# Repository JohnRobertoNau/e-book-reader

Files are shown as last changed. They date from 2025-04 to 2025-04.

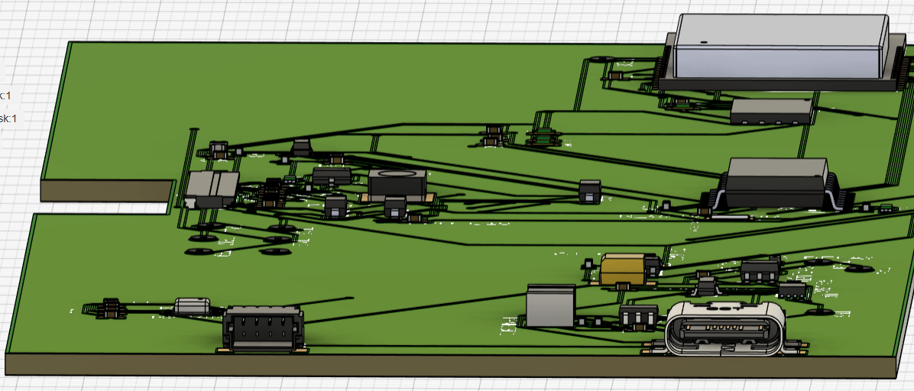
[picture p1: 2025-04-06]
Images/placa-3d-cu-componente_2.png

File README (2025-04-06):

Schema bloc si fisierul BOM se gasesc aici:
https://drive.google.com/drive/u/0/folders/1svHynGlwr7JKA02n5Jt7F-PYmH98pda1

Toate componentele au fost procurate de pe urmatoarele site-uri:
https://eu.mouser.com/
https://www.comet.srl.ro/

-------------------------------------------------------------------------------
Examinare 3D a dispozitivului:
 - pentru a vedea in Fusion ce este in spatele ecranului:
    apasa Hide pe Browser -> Bodies -> Box: vei vedea placuta si bateria

- Sketch 43 reprezinta bateria
- Sketch 44 reprezinta ecranul
- Pentru a vedea imagini cu dispozitivul cauta in directorul Images al acestui
repository

-------------------------------------------------------------------------------
Descriere Proiect:

OpenBook este un e-book reader open-source implementat pentru o citire simpla a
cartilor electronice. Pentru elaborarea acestui proiect au fost folosite
componente din biblioteca deskassistant. Erorile au fost verificate cu ajutorul
unui fisier de tip ".drc". Principala componenta este un microcontroller
ESP32-C6. Intregului dispozititv ii este asociat o baterie si un ecran, toate
acestea fiind amplasate intr-o carcasa, fiind vizibile in directorul Mechanical

-------------------------------------------------------------------------------
Componente Hardware folosite:
- ESP32-C6: Microcontroller principal, care asigura conectivitatea si
procesarea datelor.
- E-Paper Display: Display cu consum redus de energie, conectat prin
interfața SPI.
- Senzor de Mediu BME688: Masoara parametrii de mediu și trimite date
prin interfața I2C.
- Memorie NOR Flash 64MB: Stocare extensibila pentru fișiere de e-book.
- Modul RTC DS3231SN: Ofera funcționalitate de ceas în timp real.
- Conector USB-C: Incarcare și transfer de date.
- Baterie Li-Po: Alimentare principala a dispozitivului.
- Conectori pentru SD Card: Pentru extinderea memoriei si stocarea cartilor.

-------------------------------------------------------------------------------
ESP32-C6:
 - GPIO pinii sunt utilizați pentru conectarea senzorilor și a altor componente periferice.
 - SPI pentru E-Paper și memorie Flash.
 - I2C pentru senzorul de mediu.

Interfețe principale:
 - SPI: Conecteaza ecranul E-Paper și memoria Flash.
 - I2C: Conectează senzorul BME688 și modulul RTC.
 - UART: Pentru comunicație seriala.

Pini Utilizați - ESP32-C6:
 - GPIO16: TX pentru comunicație serială.
 - GPIO17: RX pentru comunicație serială.
 - GPIO21: SDA pentru I2C.
 - GPIO22: SCL pentru I2C.
 - GPIO18, GPIO19: SCK și MISO pentru SPI.
 - GPIO5: Chip Select pentru memorie Flash.
 - GPIO4: Reset pentru E-Paper.

 ------------------------------------------------------------------------------
 Probleme si gestionarea erorilor:

  - A fost necesara aprobarea a 2 erori de tip "smd-hole", deoarece piesa
  pentru J3 era defecta.
  - Pentru TP-uri a trebuit sa implementez propriul design.
  - Folosirea de VIAS-uri pentru a evita intersectia cablurilor.

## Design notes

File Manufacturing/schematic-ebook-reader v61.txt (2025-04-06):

Partlist exported from Fusion Hub: john   Project: Admin Project  Board: schematic-ebook-reader v61 at 4/6/2025 5:17 PM

Qty Value                                                                          Device                                                                         Package                                                Parts                                                                                                  Description                                                                                                                                                                                                                                                                                                                                                                                                                                                                                          ARROW_PART_NUMBER ARROW_PRICE-STOCK AVAILABILITY CENTROID_NOT_SPECIFIED CHECK_PRICES                                                                           COPYRIGHT                                                DATASHEET                              DESCRIPTION                                                                                        DIGIKEY_DESCRIPTION                                                                                                                                                                                                      DIGIKEY_PART_NUMBER                           HEIGHT                                                                                LEAD_FREE                                                          MANUFACTURER_NAME                 MANUFACTURER_PART_NUMBER MF                  MFR_NAME          MOUSER_PART_NUMBER    MOUSER_PRICE-STOCK                                                                                        MOUSER_TESTING_PART_NUMBER MOUSER_TESTING_PRICE-STOCK MP                                                                                                                  MPN                                                                                                  PACKAGE                     POPULARITY          PREFIX PRICE                        PROD_ID    PURCHASE-URL                                                                                                                                ROHS SNAPEDA_LINK                                                                       SPICEMODEL                                                                                                                                      SPICEPREFIX TEMPERATURE_RANGE_HIGH                                                                  TEMPERATURE_RANGE_LOW TP_SIGNAL_NAME VALUE             
1                                                                                  ADAFRUIT_LEDCHIP-LED0603                                                       ADAFRUIT_CHIP-LED0603                                  GHC_LED                                                                                                LED                                                                                                                                                                                                                                                                                                                                                                                                                                                                                                                                                                                                                                                                                                                                                                                                                                                                                                                                                                                                                                                                                                                                                                                                                                                                                                                                                                                                                                                                                                                                                                                                                                                                                                                                                                                                                                                                                                                                                                                                                                                                                                                                                                                                                                                                                                                                                                                                                                                                  
1                                                                                  SJ                                                                             SJ                                                     SJ1                                                                                                    SMD solder JUMPER                                                                                                                                                                                                                                                                                                                                                                                                                                                                                                                                                                                                                                                                                                                                                                                                                                                                                                                                                                                                                                                                                                                                                                                                                                                                                                                                                                                                                                                                                                                                                                                                                                                                                                                                                                                                                                  3                                                                                                                                                                                                                                                                                                                                                                                                                                                                                                                                                                                                                 
1   0.1uF/50V                                                                      ESP32_WROVER_EAGLE-LTSPICE_CC0402                                              ESP32_WROVER_EAGLE-LTSPICE_C0402                       EPD_C5                                                                                                 CAPACITOR, European symbol                                                                                                                                                                                                                                                                                                                                                                                                                                                                                                                                                                                                                                                                                                                                                                                                                                                                                                                                                                                                                                                                                                                                                                                                                                                                                                                                                                                                                                                                                                                                                                                                                                                                                                                                                                                                                                                                                                                                                                                                                                                                                                                                NONE                                                                                                                                            C                                                                                                                                                          
1   0.47                                                                           ESP32_WROVER_EAGLE-LTSPICE_RR0402                                              ESP32_WROVER_EAGLE-LTSPICE_C0402                       R3                                                                                                     RESISTOR, European symbol                                                                                                                                                                                                                                                                                                                                                                                                                                                                                                                                                                                                                                                                                                                                                                                                                                                                                                                                                                                                                                                                                                                                                                                                                                                                                                                                                                                                                                                                                                                                                                                                                                                                                                                                                                                                                                                                                                                                                                                                                                                                                                                                 NONE                                                                                                                                            R                                                                                                                                                          
1   100k                                                                           ESP32_WROVER_EAGLE-LTSPICE_RR0402                                              ESP32_WROVER_EAGLE-LTSPICE_C0402                       R1_PWRUSB                                                                                              RESISTOR, European symbol                                                                                                                                                                                                                                                                                                                                                                                                                                                                                                                                                                                                                                                                                                                                                                                                                                                                                                                                                                                                                                                                                                                                                                                                                                                                                                                                                                                                                                                                                                                                                                                                                                                                                                                                                                                                                                                                                                                                                                                                                                                                                                                                 NONE                                                                                                                                            R                                                                                                                                                          
8   100nF                                                                          ESP32_WROVER_EAGLE-LTSPICE_CC0402                                              ESP32_WROVER_EAGLE-LTSPICE_C0402                       C1, C2, C4_USB, C6, C8, C9, C10, C_DELAY                                                               CAPACITOR, European symbol                                                                                                                                                                                                                                                                                                                                                                                                                                                                                                                                                                                                                                                                                                                                                                                                                                                                                                                                                                                                                                                                                                                                                                                                                                                                                                                                                                                                                                                                                                                                                                                                                                                                                                                                                                                                                                                                                                                                                                                                                                                                                                                                NONE                                                                                                                                            C                                                                                                                                                          
1   100uF                                                                          RCL_CPOL-EUCT3528                                                              RCL_CT3528                                             C3                                                                                                     POLARIZED CAPACITOR, European symbol                                                                                                                                                                                                                                                                                                                                                                                                                                                                                                                                                                                                                                                                                                                                                                                                                                                                                                                                                                                                                                                                                                                                                                                                                                                                                                                                                                                                                                                                                                                                                                                                                                                                                                                                                                                                               0                                                                                                                                                                                                                                                                                                                                                                                                                                                      C                                                                                                                                                          
16  10k                                                                            ESP32_WROVER_EAGLE-LTSPICE_RR0402                                              ESP32_WROVER_EAGLE-LTSPICE_C0402                       R1, R1-PINH, R1_PINH1, R2-PINH, R2-PINH1, R4, R5, R6, R7, R8, R9, R10, R_BOOT, R_CHANGE, R_CL1, R_REST RESISTOR, European symbol                                                                                                                                                                                                                                                                                                                                                                                                                                                                                                                                                                                                                                                                                                                                                                                                                                                                                                                                                                                                                                                                                                                                                                                                                                                                                                                                                                                                                                                                                                                                                                                                                                                                                                                                                                                                                                                                                                                                                                                                                                                                                                                                 NONE                                                                                                                                            R                                                                                                                                                          
1   10uF                                                                           ESP32_WROVER_EAGLE-LTSPICE_CC0402                                              ESP32_WROVER_EAGLE-LTSPICE_C0402                       C7                                                                                                     CAPACITOR, European symbol                                                                                                                                                                                                                                                                                                                                                                                                                                                                                                                                                                                                                                                                                                                                                                                                                                                                                                                                                                                                                                                                                                                                                                                                                                                                                                                                                                                                                                                                                                                                                                                                                                                                                                                                                                                                                                                                                                                                                                                                                                                                                                                                NONE                                                                                                                                            C                                                                                                                                                          
1   112A-TAAR-R03_ATTEND                                                           112A-TAAR-R03_ATTEND                                                           112ATAARR03ATTEND                                      J4                                                                                                     Micro SD Card Socket, Push-Push Type, Top Mount, SMT, H=1.83mm, 10u                                                                                                                                                                                                                                                                                                                                                                                                                                                                                                                                                                                                                                                                                                 Micro SD Card Socket                                                                                Push-Push Type                                                                                                                                                                                                           Top Mount                                     SMT                                                                                   H=1.83mm                                                           10u                                                                           1.9mm                                   ATTEND                                                                                                    112A-TAAR-R03 ATTEND                                                                                                                                                                                                                                                                                                                                                                                                                                                                                                                                                                                                                                                                                                                                                                                                                                                                                                         
1   15                                                                             ESP32_WROVER_EAGLE-LTSPICE_RR0402                                              ESP32_WROVER_EAGLE-LTSPICE_C0402                       R_CAPACITOR                                                                                            RESISTOR, European symbol                                                                                                                                                                                                                                                                                                                                                                                                                                                                                                                                                                                                                                                                                                                                                                                                                                                                                                                                                                                                                                                                                                                                                                                                                                                                                                                                                                                                                                                                                                                                                                                                                                                                                                                                                                                                                                                                                                                                                                                                                                                                                                                                 NONE                                                                                                                                            R                                                                                                                                                          
1   1uF                                                                            ESP32_WROVER_EAGLE-LTSPICE_CC0402                                              ESP32_WROVER_EAGLE-LTSPICE_C0402                       C5                                                                                                     CAPACITOR, European symbol                                                                                                                                                                                                                                                                                                                                                                                                                                                                                                                                                                                                                                                                                                                                                                                                                                                                                                                                                                                                                                                                                                                                                                                                                                                                                                                                                                                                                                                                                                                                                                                                                                                                                                                                                                                                                                                                                                                                                                                                                                                                                                                                NONE                                                                                                                                            C                                                                                                                                                          
9   1uF/50V                                                                        ESP32_WROVER_EAGLE-LTSPICE_CC0402                                              ESP32_WROVER_EAGLE-LTSPICE_C0402                       EPD_C1, EPD_C2, EPD_C6, EPD_C7, EPD_C8, EPD_C9, EPD_C10, EPD_C11, EPD_C12                              CAPACITOR, European symbol                                                                                                                                                                                                                                                                                                                                                                                                                                                                                                                                                                                                                                                                                                                                                                                                                                                                                                                                                                                                                                                                                                                                                                                                                                                                                                                                                                                                                                                                                                                                                                                                                                                                                                                                                                                                                                                                                                                                                                                                                                                                                                                                NONE                                                                                                                                            C                                                                                                                                                          
1   2.2                                                                            ESP32_WROVER_EAGLE-LTSPICE_RR0402                                              ESP32_WROVER_EAGLE-LTSPICE_C0402                       R2                                                                                                     RESISTOR, European symbol                                                                                                                                                                                                                                                                                                                                                                                                                                                                                                                                                                                                                                                                                                                                                                                                                                                                                                                                                                                                                                                                                                                                                                                                                                                                                                                                                                                                                                                                                                                                                                                                                                                                                                                                                                                                                                                                                                                                                                                                                                                                                                                                 NONE                                                                                                                                            R                                                                                                                                                          
1   200                                                                            ESP32_WROVER_EAGLE-LTSPICE_RR0402                                              ESP32_WROVER_EAGLE-LTSPICE_C0402                       R1_BAT                                                                                                 RESISTOR, European symbol                                                                                                                                                                                                                                                                                                                                                                                                                                                                                                                                                                                                                                                                                                                                                                                                                                                                                                                                                                                                                                                                                                                                                                                                                                                                                                                                                                                                                                                                                                                                                                                                                                                                                                                                                                                                                                                                                                                                                                                                                                                                                                                                 NONE                                                                                                                                            R                                                                                                                                                          
2   20V/4.2A/52m?/1.4W                                                             ESP32_WROVER_SPARKFUN-DISCRETESEMI_MOSFET_PCH-DMG2305UX-7                      ESP32_WROVER_SPARKFUN-DISCRETESEMI_SOT23-3             Q1, Q2                                                                                                 P-channel MOSFETs                                                                                                                                                                                                                                                                                                                                                                                                                                                                                                                                                                                                                                                                                                                                                                                                                                                                                                                                                                                                                                                                                                                                                                                                                                                                                                                                                                                                                                                                                                                                                                                                                                                                                                                                                                                                                                                                                          TRAN-14388                                                                                                                                                                                                                                                                                                                                                                                                                                                                                                                              20V/4.2A/52m?/1.4W
1   2k                                                                             ESP32_WROVER_EAGLE-LTSPICE_RR0402                                              ESP32_WROVER_EAGLE-LTSPICE_C0402                       R2_BAT                                                                                                 RESISTOR, European symbol                                                                                                                                                                                                                                                                                                                                                                                                                                                                                                                                                                                                                                                                                                                                                                                                                                                                                                                                                                                                                                                                                                                                                                                                                                                                                                                                                                                                                                                                                                                                                                                                                                                                                                                                                                                                                                                                                                                                                                                                                                                                                                                                 NONE                                                                                                                                            R                                                                                                                                                          
5   4.7uF                                                                          ESP32_WROVER_EAGLE-LTSPICE_CC0402                                              ESP32_WROVER_EAGLE-LTSPICE_C0402                       C1_BAT, C1_BAT1, C1_BAT2, C2_BAT, C5_USB                                                               CAPACITOR, European symbol                                                                                                                                                                                                                                                                                                                                                                                                                                                                                                                                                                                                                                                                                                                                                                                                                                                                                                                                                                                                                                                                                                                                                                                                                                                                                                                                                                                                                                                                                                                                                                                                                                                                                                                                                                                                                                                                                                                                                                                                                                                                                                                                NONE                                                                                                                                            C                                                                                                                                                          
1   4.7uF/25V                                                                      ESP32_WROVER_EAGLE-LTSPICE_CC0402                                              ESP32_WROVER_EAGLE-LTSPICE_C0402                       C4                                                                                                     CAPACITOR, European symbol                                                                                                                                                                                                                                                                                                                                                                                                                                                                                                                                                                                                                                                                                                                                                                                                                                                                                                                                                                                                                                                                                                                                                                                                                                                                                                                                                                                                                                                                                                                                                                                                                                                                                                                                                                                                                                                                                                                                                                                                                                                                                                                                NONE                                                                                                                                            C                                                                                                                                                          
2   5k1                                                                            ESP32_WROVER_EAGLE-LTSPICE_RR0402                                              ESP32_WROVER_EAGLE-LTSPICE_C0402                       R2-USB, R2-USB1                                                                                        RESISTOR, European symbol                                                                                                                                                                                                                                                                                                                                                                                                                                                                                                                                                                                                                                                                                                                                                                                                                                                                                                                                                                                                                                                                                                                                                                                                                                                                                                                                                                                                                                                                                                                                                                                                                                                                                                                                                                                                                                                                                                                                                                                                                                                                                                                                 NONE                                                                                                                                            R                                                                                                                                                          
1   68uF                                                                           744043680IND_4828-WE-TPC_WRE                                                   IND_4828-WE-TPC_WRE                                    L1                                                                                                                                                                                                                                                                                                                                                                                                                                                                                                                                                                                                                                                                                                                                                                         Copyright (C) 2024 Ultra Librarian. All rights reserved.                                                                                                                                                                                                                                                                                                                                                                                                                                                                                                                                                                                                             744043680                                    Wurth Electronics                                                                                                                                                                                                                                                                                                                                                                                                                                                                                                                                                                                                                                                                                                                                                                                                                                                                                                                                                                                                                                                              
1   BD5229G-TR                                                                     BD5229G-TR                                                                     SOT95P280X125-5N                                       IC1                                                                                                    Voltage Detector with Adjustable Delay Time: CMOS processes are utilized to develop high precision, low current consumption CMOS reset ICs that allow arbitrary setting of the delay time. The extensive lineup includes both Nch Open Drain and CMOS output types in a wide range of detection voltages (from 2.3V to 6.0V, in 0.1V steps), enabling selection of the ideal solution based on customer requirements. In addition, the entire series is of course both lead-free and RoHS-compliant.                                                                                                                                                                                                                                                                Voltage Detector with Adjustable Delay Time: CMOS processes are utilized to develop high precision  low current consumption CMOS reset ICs that allow arbitrary setting of the delay time. The extensive lineup includes both Nch Open Drain and CMOS output types in a wide range of detection voltages (from 2.3V to 6.0V  in 0.1V steps)                                enabling selection of the ideal solution based on customer requirements. In addition  the entire series is of course both lead-free and RoHS-compliant.                                                            1.25mm                                ROHM Semiconductor    BD5229G-TR                                                                                                                                                      755-BD5229G-TR                                                                                                      https://www.mouser.co.uk/ProductDetail/ROHM-Semiconductor/BD5229G-TR?qs=4kLU8WoGk0vvnhrrYwdszw%3D%3D                                                                                                                                                                                                                                                                                                                                                                                                                                                                                                                                                                                                                                               
3   BUTTON_CUSYOMV1                                                                BUTTON_CUSYOMV1                                                                MYBUTTON                                               BOOT_BUTTON, CHANGE_BUTTON, REST_BUTTON                                                                                                                                                                                                                                                                                                                                                                                                                                                                                                                                                                                                                                                                                                                                                                                                                                                                                                                                                                                                                                                                                                                                                                                                                                                                                                                                                                                                                                                                                                                                                                                                                                                                                                                                                                                                                                                                                                                                                                                                                                                                                                                                                                                                                                                                                                                                                                                                                                                                                                                                     
1   CPH3225A                                                                       CPH3225A                                                                       CAPCP3225X100N                                         C10_SUPERCAP                                                                                           Cap 0.011F 3.3V 1210 Flat Check availability                                                                                                                                                                                                                                                                                                                                                                                                                                                                                             Not in stock                        https://www.snapeda.com/parts/CPH3225A/Seiko+Instruments/view-part/?ref=eda                                                                                                             11 mF (EDLC) Supercapacitor 3.3 V 1210 (3225 Metric) - -                                                                                                                                                                                                                                                                                                                                                                                                                                                                                                                                     Seiko Instruments                                                                                                                                                                                                           CPH3225A                                                                                                                                                                                                                 1210 Seiko                                             None                                    https://www.snapeda.com/api/url_track_click_mouser/?unipart_id=562593&manufacturer=Seiko Instruments&part_name=CPH3225A&search_term=None         https://www.snapeda.com/parts/CPH3225A/Seiko+Instruments/view-part/?ref=snap                                                                                                                                                                                                                                                                                                                  
1   DS3231SN#                                                                      DS3231SN#                                                                      SOIC127P1032X265-16N                                   U3                                                                                                     Real Time Clock Serial 16-Pin SOIC W T/R     Check availability                                                                                                                                                                                                                                                                                                                                                                                                                                                                          In Stock                            https://www.snapeda.com/parts/DS3231SN%23/Analog+Devices/view-part/?ref=eda                                                                                                             Extremely Accurate I2C-Integrated RTC/TCXO/Crystal                                                                                                                                                                                                                                                                                                                                                                                                                                                                                                                                           Analog Devices                                                                                                                                                                                                              DS3231SN#                                                                                                                                                                                                                SOIC-16 Maxim                                          None                                    https://www.snapeda.com/api/url_track_click_mouser/?unipart_id=99048&manufacturer=Analog Devices&part_name=DS3231SN#&search_term=None            https://www.snapeda.com/parts/DS3231SN%23/Analog+Devices/view-part/?ref=snap                                                                                                                                                                                                                                                                                                                  
1   ESP32-C6-WROOM-1-N8                                                            ESP32-C6-WROOM-1-N8                                                            XCVR_ESP32-C6-WROOM-1-N8                               U2                                                                                                     Check availability                                                                                                                                                                                                                                                                                                                                                                                                                                                                                                                       In Stock                            https://www.snapeda.com/parts/ESP32-C6-WROOM-1-N8/Espressif+Systems/view-part/?ref=eda                                                                                                  Multiprotocol Modules ESP32-C6 module                                                              Wi-Fi 6 in 2.4 GHz band                                                                                                                                                                                                  Bluetooth 5                                   Zigbee 3.0 and Thread. ESP34-WROOM Compatible - ENGINEERING SAMPLE                                                                                                                                                                                                             Espressif Systems                                                                                                                                                                                                                                                                                                                                                                                                    ESP32-C6-WROOM-1-N8        None                                                                                                                                                                                None                                                                                                                                                                                                                                                https://www.snapeda.com/parts/ESP32-C6-WROOM-1-N8/Espressif+Systems/view-part/?ref=snap                                                        
1   ESP32C6_VARISTORCN1812                                                         ESP32C6_VARISTORCN1812                                                         ESP32C6_VARISTOR_CT/CN1812                             PFMF.050.1                                                                                             VARISTOR                                                                                                                                                                                                                                                                                                                                                                                                                                                                                                                                                                                                                                                                                                                                                                                                                                                                                                                                                                                                                                                                                                                                                                                                                                                                                                                                                                                                                                                                                                                                                                                                                                                                                                                                                                                                                                           0                                                                                                                                                                                                                                                                                                                                                                                                                                                                                                                                                                                                                 
2   ESP32_WROVER_AVX---SD0805S020S1R0_AVX_SD0805S020S1R0_0_0AVX_SD0805S020S1R0_0_0 ESP32_WROVER_AVX---SD0805S020S1R0_AVX_SD0805S020S1R0_0_0AVX_SD0805S020S1R0_0_0 ESP32_WROVER_AVX---SD0805S020S1R0_AVX_SD0805S020S1R0_0 D2, D7                                                                                                 Schottky Barrier Rectifier Diode                                                                                                                                                                                                                                                                                                                                                                                                                                                                                                                      No                                                                                                                                                                     http://datasheets.avx.com/schottky.pdf                                                                                                    DIODE SCHOTTKY 20V 1A 0805                                                                                                                                                                                               478-7800-1-ND                                                                                                                       yes                                                                                                                           AVX                                   581-SD0805S020S1R0                                                                                                                                                                                                                                                                                                                                                                                             0805 (2012 metric)                              D                                                                                                                                                                                          yes                                                                                                                                                                                                                                                 +125°C                                                                                  -55°C                                                  
1   ESP32_WROVER_BME680_BME680                                                     ESP32_WROVER_BME680_BME680                                                     ESP32_WROVER_BME680_PSON80P300X300X100-8N              SENSOR2                                                                                                Integrated Environmental Unit                                                                                                                                                                                                                                                                                                                                                                                                                                                                                                            Unavailable                                                                                                                                                                                                                 Integrated Environmental Unit                                                                                                                                                                                                                                                                                                                                                                                                                                                                                                                                                                Bosch Sensortec                                                                                                                                                                                                             BME680                                                                                                                                                                                                                   LGA-8 Bosch Tools                                      None                                                                                                                                                                                                                                                                                                                                                                                                                                                                                                                                                                                   
1   ESP32_WROVER_SPARKFUN-IC-POWER_MCP73831                                        ESP32_WROVER_SPARKFUN-IC-POWER_MCP73831                                        ESP32_WROVER_SPARKFUN-IC-POWER_SOT23-5                 MCP73831                                                                                               MCP73831T Li-Ion, Li-Pol Controller                                                                                                                                                                                                                                                                                                                                                                                                                                                                                                                                                                                                                                                                                                                                                                                                                                                                                                                                                                                                                                                                                                                                                                                                                                                                                                                                                                                                                                                                                                                                                                                                                                                                                                                                                                                                                                                                        IC-09995                                                                                                                                                                                                                                                                                                                                                                                                                                                                                                                                                  
1   FH34SRJ-24S-0.5SH_99_                                                          FH34SRJ-24S-0.5SH_99_                                                          FH34SRJ24S05SH99                                       J1                                                                                                     24 Position FFC, FPC Connector Contacts, Top and Bottom 0.020" (0.50mm) Surface Mount, Right Angle                                                                                                                                                                                                                                                                                                                                                                                                                                                                                                                                                                                                                                                                  24 Position FFC                                                                                     FPC Connector Contacts                                                                                                                                                                                                   Top and Bottom 0.020" (0.50mm) Surface Mount  Right Angle                                                                                                                                                                               1.1mm                                        Hirose            FH34SRJ-24S-0.5SH(99)                                                                                                                                      798-FH34SRJ24S05SH99       https://www.mouser.co.uk/ProductDetail/Hirose-Connector/FH34SRJ-24S-0.5SH99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                                                                                                                                                                                                                                                                                                                                                                                                                                                                                                                                                                                                                                                                                                                                                    
1   MAX17048G+T10                                                                  MAX17048G+T10                                                                  SON50P200X200X80-9N                                    U4                                                                                                     Check availability                                                                                                                                                                                                                                                                                                                                                                                                                                                                                                                       In Stock                            https://www.snapeda.com/parts/MAX17048G+T10/Analog+Devices/view-part/?ref=eda                                                                                                           3µA 1-Cell/2-Cell Fuel Gauge with ModelGauge                                                                                                                                                                                                                                                                                                                                                                                                                                                                                                                                                 Analog Devices                                                                                                                                                                                                              MAX17048G+T10                                                                                                                                                                                                            TDFN-8 Maxim                                           None                                    https://www.snapeda.com/api/url_track_click_mouser/?unipart_id=329239&manufacturer=Analog Devices&part_name=MAX17048G+T10&search_term=None       https://www.snapeda.com/parts/MAX17048G+T10/Analog+Devices/view-part/?ref=snap                                                                                                                                                                                                                                                                                                                
3   MBR0530                                                                        MBR0530                                                                        SOD3716X135N                                           D3, D4, D5                                                                                             ON SEMICONDUCTOR - MBR0530 - DIODE, SCHOTTKY, 0.5A, 30V, SOD-123                                                                                                                                                                                                                                                                                                                                                                                                                                                                         In Stock                            https://www.snapeda.com/parts/MBR0530/Onsemi/view-part/?ref=eda                                                                                                                         Diode Schottky 30 V 500mA Surface Mount SOD-123                                                                                                                                                                                                                                                                                                                                                                                                                                                                                                                                              ON Semiconductor                                                                                                                                                                                                            MBR0530                                                                                                                                                                                                                  SOD-123-2 ON Semiconductor                             None                                    https://www.snapeda.com/api/url_track_click_mouser/?unipart_id=179458&manufacturer=ON Semiconductor&part_name=MBR0530&search_term=None           https://www.snapeda.com/parts/MBR0530/Onsemi/view-part/?ref=snap                                                                                                                                                                                                                                                                                                                              
6   PGB1010603MR                                                                   PGB1010603MR                                                                   DIOC1608X36N                                           D6, D8, D9, D10, D11, D12                                                                              Check availability                                                                                                                                                                                                                                                                                                                                                                                                                                                                                                                       In Stock                            https://www.snapeda.com/parts/PGB1010603MR/Littelfuse/view-part/?ref=eda                                                                                                                150V (Typ) Clamp - Ipp Tvs Diode Surface Mount 0603 (1608 Metric)                                                                                                                                                                                                                                                                                                                                                                                                                                                                                                                            Littelfuse Inc.                                                                                                                                                                                                             PGB1010603MR                                                                                                                                                                                                             0603 Littelfuse Inc.                                   None                                    https://www.snapeda.com/api/url_track_click_mouser/?unipart_id=5659453&manufacturer=Littelfuse Inc.&part_name=PGB1010603MR&search_term=None      https://www.snapeda.com/parts/PGB1010603MR/Littelfuse/view-part/?ref=snap                                                                                                                                                                                                                                                                                                                     
1   QWIIC_RIGHT_ANGLE                                                              QWIIC_CONNECTORJS-1MM                                                          JST04_1MM_RA                                           J3                                                                                                     SparkFun I2C Standard Qwiic Connector                                                                                                                                                                                                                                                                                                                                                                                                                                                                                                                                                                                                                                                                                                                                                                                                                                                                                                                                                                                                                                                                                                                                                                                                                                                                                                                                                                                                                                                                                                                                                                                                                                                                                                                                                                                                                                                                      CONN-13694                                                                                                                                                                                                                                                                                                                                                                                                                                                                                                                              QWIIC_RIGHT_ANGLE 
1   SAMACSYS_PARTS_USB4110-GF-A                                                    SAMACSYS_PARTS_USB4110-GF-A                                                    SAMACSYS_PARTS_USB4110GFA                              J2                                                                                                     CONN USB 2.0 TYPE-C R/A SMT                                                                                                                                                                                                                                                                                                                                                                                                                                                                                                                                                                                                                                                                                                                                         CONN USB 2.0 TYPE-C R/A SMT                                                                                                                                                                                                                                                                                                                                               3.26mm                                                                                                                                                   GCT (GLOBAL CONNECTOR TECHNOLOGY) USB4110-GF-A                                                   640-USB4110-GF-A      https://www.mouser.co.uk/ProductDetail/GCT/USB4110-GF-A?qs=KUoIvG%2F9IlYiZvIXQjyJeA%3D%3D
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

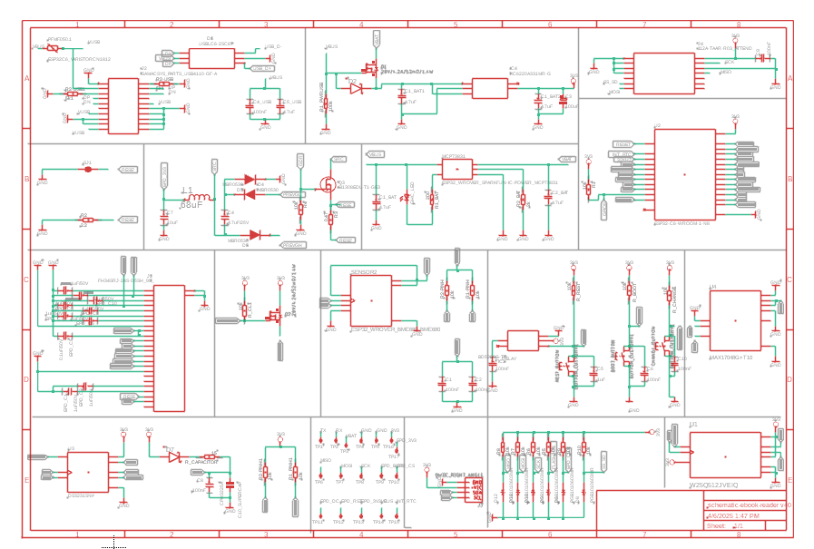
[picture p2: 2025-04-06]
Images/schematic.png

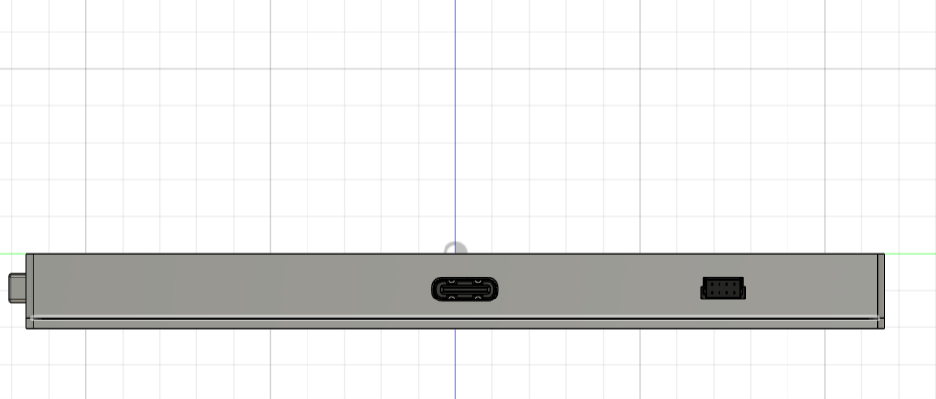
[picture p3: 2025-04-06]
Images/porturi-laterale+butoane.png

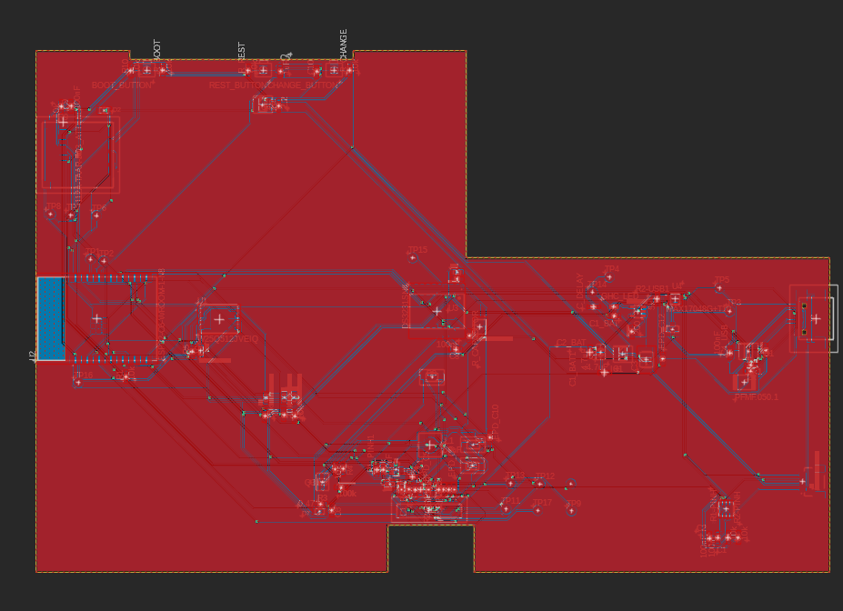
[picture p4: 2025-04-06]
Images/pcb-cu-plan-de-masa.png

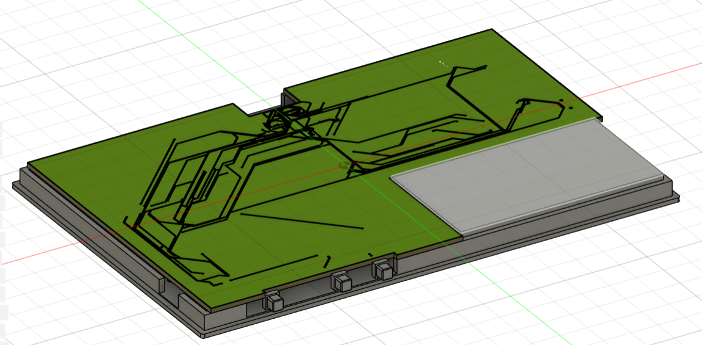
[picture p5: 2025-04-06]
Images/placuta+baterie-in-carcasa.png

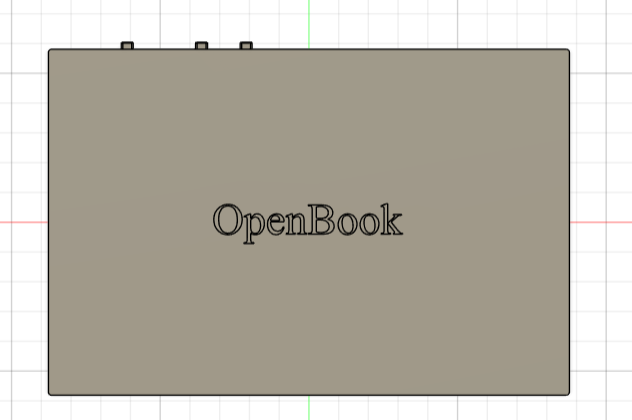
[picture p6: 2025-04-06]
Images/spatele-produsului.png

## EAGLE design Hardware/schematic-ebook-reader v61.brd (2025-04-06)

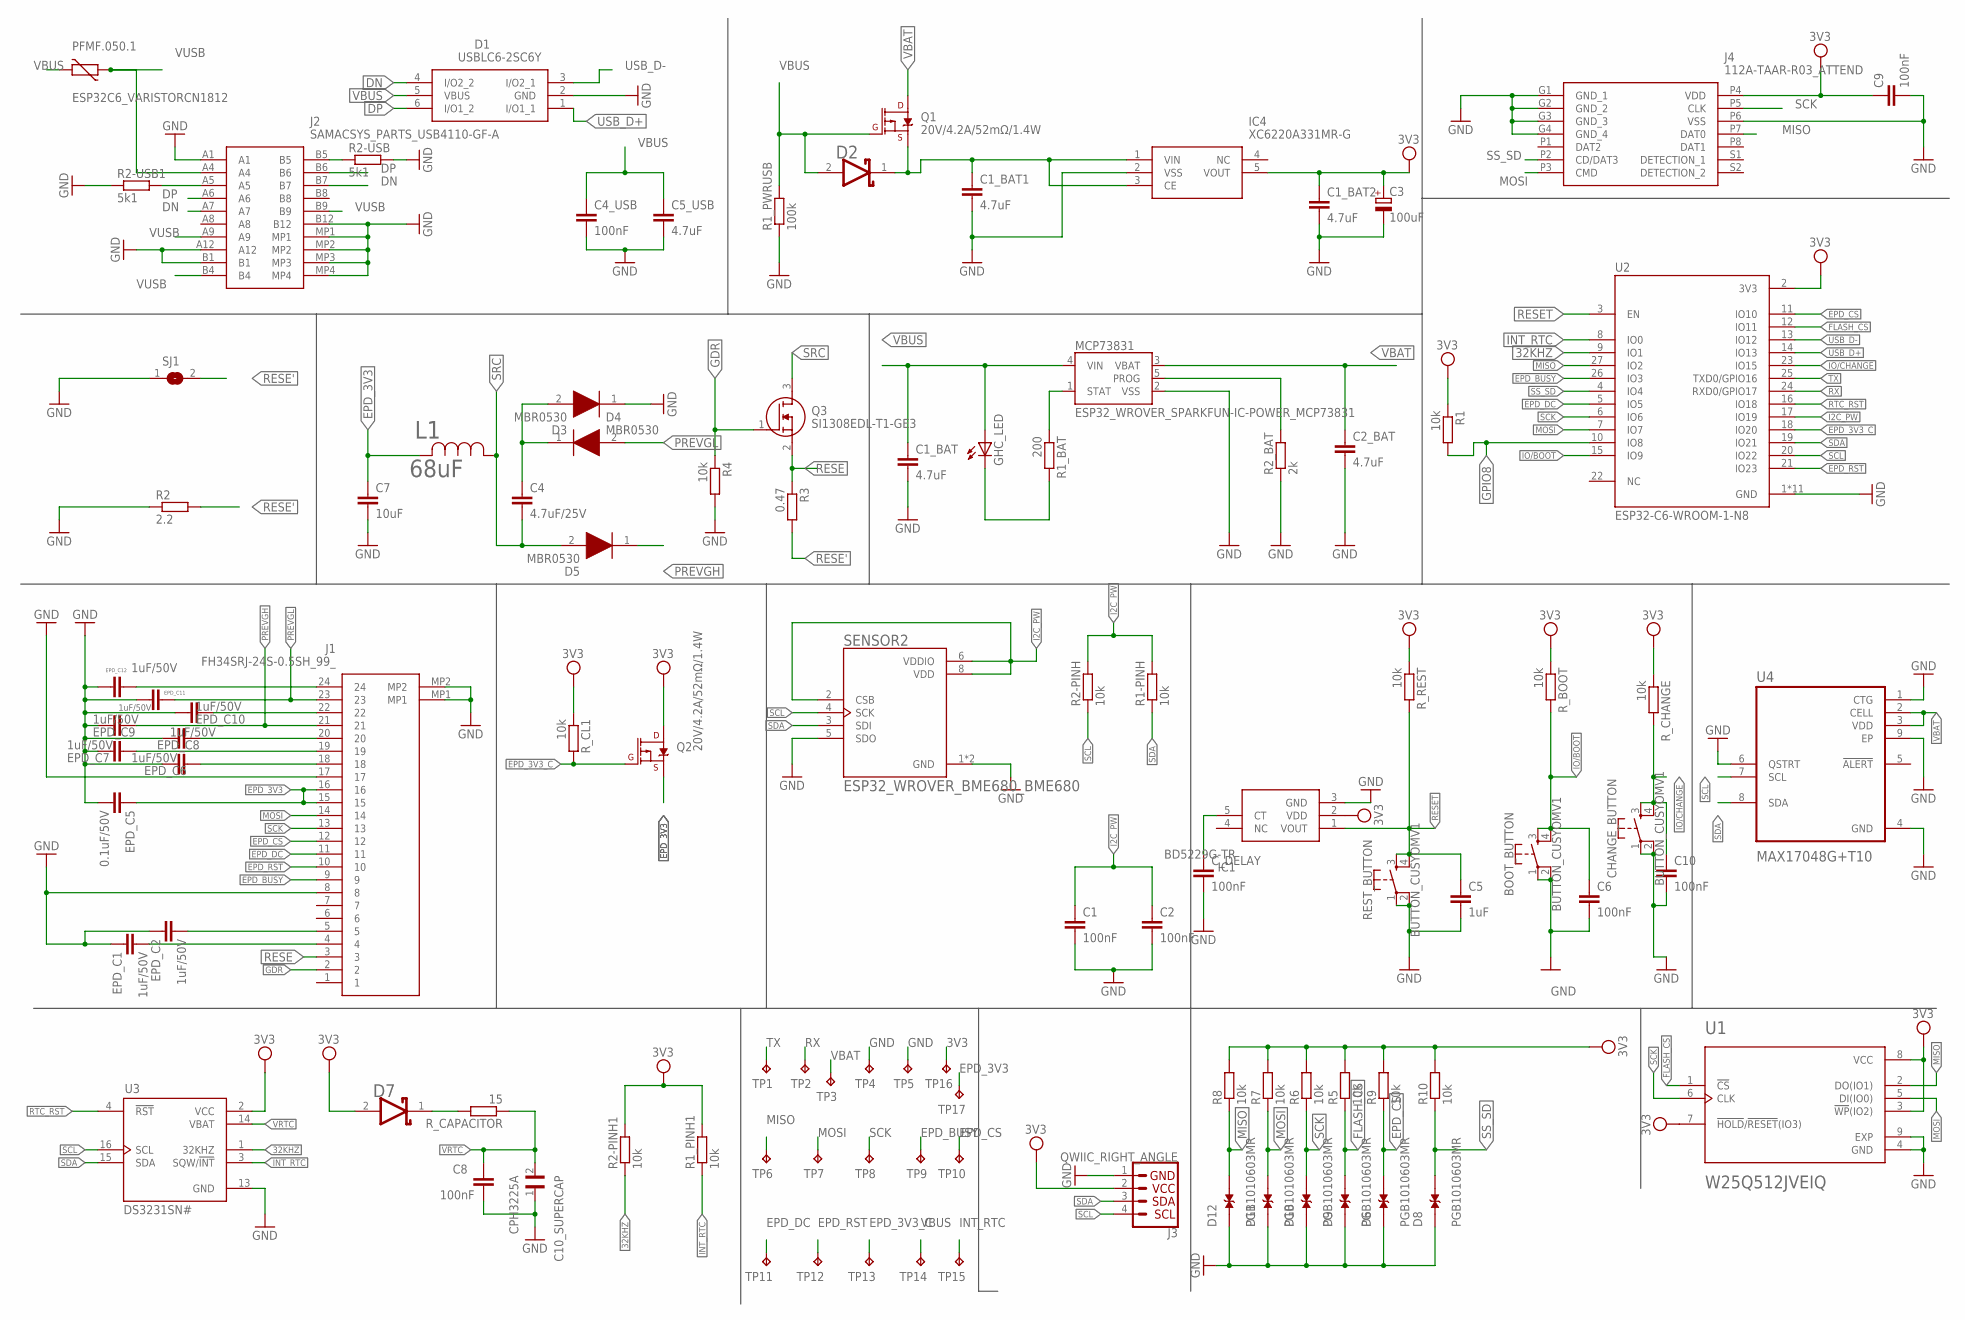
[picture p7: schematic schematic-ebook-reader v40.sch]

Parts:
BOOT_BUTTON: BUTTON_CUSYOMV1; MYBUTTON
C1, C2, C4_USB, C6, C8, C9, C10: 100nF; ESP32_WROVER_EAGLE-LTSPICE_C0402
C1_BAT, C1_BAT1, C1_BAT2, C2_BAT, C5_USB: 4.7uF; ESP32_WROVER_EAGLE-LTSPICE_C0402
C3: 100uF; RCL_CT3528
C4: 4.7uF/25V; ESP32_WROVER_EAGLE-LTSPICE_C0402
C5: 1uF; ESP32_WROVER_EAGLE-LTSPICE_C0402
C7: 10uF; ESP32_WROVER_EAGLE-LTSPICE_C0402
C10_SUPERCAP: CPH3225A; CAPCP3225X100N
CHANGE_BUTTON: BUTTON_CUSYOMV1; MYBUTTON
C_DELAY: 100nF; ESP32_WROVER_EAGLE-LTSPICE_C0402
D1: USBLC6-2SC6Y; SOT95P280X145-6N
D2, D7: ESP32_WROVER_AVX---SD0805S020S1R0_AVX_SD0805S020S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; ESP32_WROVER_AVX---SD0805S020S1R0_AVX_SD0805S020S1R0_0
D3, D4, D5: MBR0530; SOD3716X135N
D6, D8, D9, D10, D11, D12: PGB1010603MR; DIOC1608X36N
EPD_C1, EPD_C2, EPD_C6, EPD_C7, EPD_C8, EPD_C9, EPD_C10, EPD_C11, EPD_C12: 1uF/50V; ESP32_WROVER_EAGLE-LTSPICE_C0402
EPD_C5: 0.1uF/50V; ESP32_WROVER_EAGLE-LTSPICE_C0402
GHC_LED: ADAFRUIT_LEDCHIP-LED0603; ADAFRUIT_CHIP-LED0603
IC1: BD5229G-TR; SOT95P280X125-5N
IC4: XC6220A331MR-G; SOT95P280X120-5N
J1: FH34SRJ-24S-0.5SH_99_; FH34SRJ24S05SH99
J2: SAMACSYS_PARTS_USB4110-GF-A; SAMACSYS_PARTS_USB4110GFA
J3: QWIIC_RIGHT_ANGLE; JST04_1MM_RA
J4: 112A-TAAR-R03_ATTEND; 112ATAARR03ATTEND
L1: 68uF; IND_4828-WE-TPC_WRE
MCP73831: ESP32_WROVER_SPARKFUN-IC-POWER_MCP73831; ESP32_WROVER_SPARKFUN-IC-POWER_SOT23-5
PFMF.050.1: ESP32C6_VARISTORCN1812; ESP32C6_VARISTOR_CT/CN1812
Q1, Q2: 20V/4.2A/52mΩ/1.4W; ESP32_WROVER_SPARKFUN-DISCRETESEMI_SOT23-3
Q3: SI1308EDL-T1-GE3; SOT65P210X110-3N
R1, R1-PINH, R1_PINH1, R2-PINH, R2-PINH1, R4, R5, R6, R7, R8, R9, R10: 10k; ESP32_WROVER_EAGLE-LTSPICE_C0402
R1_BAT: 200; ESP32_WROVER_EAGLE-LTSPICE_C0402
R1_PWRUSB: 100k; ESP32_WROVER_EAGLE-LTSPICE_C0402
R2: 2.2; ESP32_WROVER_EAGLE-LTSPICE_C0402
R2-USB, R2-USB1: 5k1; ESP32_WROVER_EAGLE-LTSPICE_C0402
R2_BAT: 2k; ESP32_WROVER_EAGLE-LTSPICE_C0402
R3: 0.47; ESP32_WROVER_EAGLE-LTSPICE_C0402
REST_BUTTON: BUTTON_CUSYOMV1; MYBUTTON
R_BOOT: 10k; ESP32_WROVER_EAGLE-LTSPICE_C0402
R_CAPACITOR: 15; ESP32_WROVER_EAGLE-LTSPICE_C0402
R_CHANGE: 10k; ESP32_WROVER_EAGLE-LTSPICE_C0402
R_CL1: 10k; ESP32_WROVER_EAGLE-LTSPICE_C0402
R_REST: 10k; ESP32_WROVER_EAGLE-LTSPICE_C0402
SENSOR2: ESP32_WROVER_BME680_BME680; ESP32_WROVER_BME680_PSON80P300X300X100-8N
SJ1: SJ
TP1, TP2, TP3, TP4, TP5, TP6, TP7, TP8, TP9, TP10, TP11, TP12, TP13, TP14, TP15, TP16, TP17: TPTP20R; TP20R
U1: W25Q512JVEIQ; SON127P600X800X80-9N
U2: ESP32-C6-WROOM-1-N8; XCVR_ESP32-C6-WROOM-1-N8
U3: DS3231SN#; SOIC127P1032X265-16N
U4: MAX17048G+T10; SON50P200X200X80-9N

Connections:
3V3: C1_BAT2.1, C3.+, C9.1, D7.2 (ANODE), IC1.2 (VDD), IC4.5 (VOUT), J3.2, J4.P4 (VDD), Q2.3 (D), R1.1, R1_PINH1.2, R2-PINH1.2, R5.2, R6.2, R7.2, R8.2, R9.2, R10.2, R_BOOT.1, R_CHANGE.1, R_CL1.1, R_REST.1, TP16.TP, U1.3 (!WP!(IO2)), U1.7 (!HOLD!/!RESET!(IO3)), U1.8 (VCC), U2.2 (3V3), U3.2 (VCC)
32KHZ: R2-PINH1.1, U2.9 (IO1), U3.1 (32KHZ)
DN: D1.4 (I/O2_2), J2.A7, J2.B7
DP: D1.6 (I/O1_2), J2.A6, J2.B6
EPD_3V3: C7.1, EPD_C5.1, J1.15, J1.16, L1.2, Q2.2 (S), TP17.TP
EPD_3V3_C: Q2.1 (G), R_CL1.2, TP13.TP, U2.18 (IO20)
EPD_BUSY: J1.9, TP9.TP, U2.26 (IO3)
EPD_CS: D6.2, J1.12, R9.1, TP10.TP, U2.11 (IO10)
EPD_DC: J1.11, TP11.TP, U2.5 (IO5)
EPD_RST: J1.10, TP12.TP, U2.21 (IO23)
FLASH_CS: D9.2, R5.1, U1.1 (!CS), U2.12 (IO11)
GDR: J1.2, Q3.1 (G), R4.1
GND: BOOT_BUTTON.1, BOOT_BUTTON.2, C1.2, C1_BAT.2, C1_BAT1.2, C1_BAT2.2, C2.2, C2_BAT.2, C3.-, C4_USB.2, C5.2, C5_USB.2, C6.2, C7.2, C8.2, C9.2, C10.2, C10_SUPERCAP.1, CHANGE_BUTTON.1, CHANGE_BUTTON.2, C_DELAY.2, D1.2 (GND), D3.1 (K), D6.1, D8.1, D9.1, D10.1, D11.1, D12.1, EPD_C1.1, EPD_C2.1, EPD_C5.2, EPD_C6.2, EPD_C7.2, EPD_C8.2, EPD_C9.2, EPD_C10.2, EPD_C11.2, EPD_C12.2, IC1.3 (GND), IC4.2 (VSS), J1.8, J1.17, J1.MP1, J1.MP2, J2.A1, J2.A12, J2.B1, J2.B12, J2.MP1, J2.MP2, J2.MP3, J2.MP4, J3.1, J4.G1 (GND_1), J4.G2 (GND_2), J4.G3 (GND_3), J4.G4 (GND_4), J4.P6 (VSS), MCP73831.2 (VSS), R1_PWRUSB.1, R2.1, R2-USB.2, R2-USB1.1, R2_BAT.1, R4.2, REST_BUTTON.1, REST_BUTTON.2, SENSOR2.1 (GND), SENSOR2.5 (SDO), SENSOR2.7 (GND), SJ1.1, TP4.TP, TP5.TP, U1.4 (GND), U1.9 (EXP), U2.1 (GND), U2.28 (GND), U2.29_1 (GND), U2.29_2 (GND), U2.29_3 (GND), U2.29_4 (GND), U2.29_5 (GND), U2.29_6 (GND), U2.29_7 (GND), U2.29_8 (GND), U2.29_9 (GND), U3.13 (GND), U4.1 (CTG), U4.4 (GND), U4.6 (QSTRT), U4.9 (EP)
GPIO8: R1.2, U2.10 (IO8)
I2C_PW: C1.1, C2.1, R1-PINH.2, R2-PINH.2, SENSOR2.2 (CSB), SENSOR2.6 (VDDIO), SENSOR2.8 (VDD), U2.17 (IO19)
INT_RTC: R1_PINH1.1, TP15.TP, U2.8 (IO0), U3.3 (SQW/!INT)
IO/BOOT: BOOT_BUTTON.3, BOOT_BUTTON.4, C6.1, R_BOOT.2, U2.15 (IO9)
IO/CHANGE: C10.1, CHANGE_BUTTON.3, CHANGE_BUTTON.4, R_CHANGE.2, U2.23 (IO15)
MISO: D12.2, J4.P7 (DAT0), R8.1, TP6.TP, U1.2 (DO(IO1)), U2.27 (IO2)
MOSI: D11.2, J1.14, J4.P3 (CMD), R7.1, TP7.TP, U1.5 (DI(IO0)), U2.7 (IO7)
unnamed: EPD_C2.2, J1.5
unnamed: J2.A5, R2-USB1.2
unnamed: J2.B5, R2-USB.1
unnamed: C1_BAT1.1, D2.1 (CATHODE), IC4.1 (VIN), IC4.3 (CE), Q1.2 (S)
unnamed: MCP73831.1 (STAT), R1_BAT.1
unnamed: C_DELAY.1, IC1.5 (CT)
unnamed: C4.1, D3.2 (A), D4.1 (K)
unnamed: MCP73831.5 (PROG), R2_BAT.2
unnamed: GHC_LED.C, R1_BAT.2
unnamed: EPD_C10.1, J1.22
unnamed: EPD_C12.1, J1.24
unnamed: EPD_C8.1, J1.20
unnamed: EPD_C7.1, J1.19
unnamed: EPD_C6.1, J1.18
unnamed: D7.1 (CATHODE), R_CAPACITOR.2
unnamed: EPD_C1.2, J1.4
PREVGH: D5.1 (K), EPD_C9.1, J1.21
PREVGL: D4.2 (A), EPD_C11.1, J1.23
RESE: J1.3, Q3.2 (S), R3.1
RESE': R2.2, R3.2, SJ1.2
RESET: C5.1, IC1.1 (VOUT), REST_BUTTON.3, REST_BUTTON.4, R_REST.2, U2.3 (EN)
RTC_RST: U2.16 (IO18), U3.4 (!RST)
RX: TP2.TP, U2.24 (RXD0/GPIO17)
SCK: D10.2, J1.13, J4.P5 (CLK), R6.1, TP8.TP, U1.6 (CLK), U2.6 (IO6)
SCL: J3.4, R2-PINH.1, SENSOR2.4 (SCK), U2.20 (IO22), U3.16 (SCL), U4.7 (SCL)
SDA: J3.3, R1-PINH.1, SENSOR2.3 (SDI), U2.19 (IO21), U3.15 (SDA), U4.8 (SDA)
SRC: C4.2, D5.2 (A), L1.1, Q3.3 (D)
SS_SD: D8.2, J4.P2 (CD/DAT3), R10.1, U2.4 (IO4)
TX: TP1.TP, U2.25 (TXD0/GPIO16)
USB_D+: D1.1 (I/O1_1), U2.14 (IO13)
USB_D-: D1.3 (I/O2_1), U2.13 (IO12)
VBAT: C2_BAT.1, MCP73831.3 (VBAT), Q1.3 (D), TP3.TP, U4.2 (CELL), U4.3 (VDD)
VBUS: C1_BAT.1, C4_USB.1, C5_USB.1, D1.5 (VBUS), D2.2 (ANODE), GHC_LED.A, MCP73831.4 (VIN), PFMF.050.1.2, Q1.1 (G), R1_PWRUSB.2, TP14.TP
VRTC: C8.1, C10_SUPERCAP.2, R_CAPACITOR.1, U3.14 (VBAT)
VUSB: J2.A4, J2.A9, J2.B4, J2.B9, PFMF.050.1.1

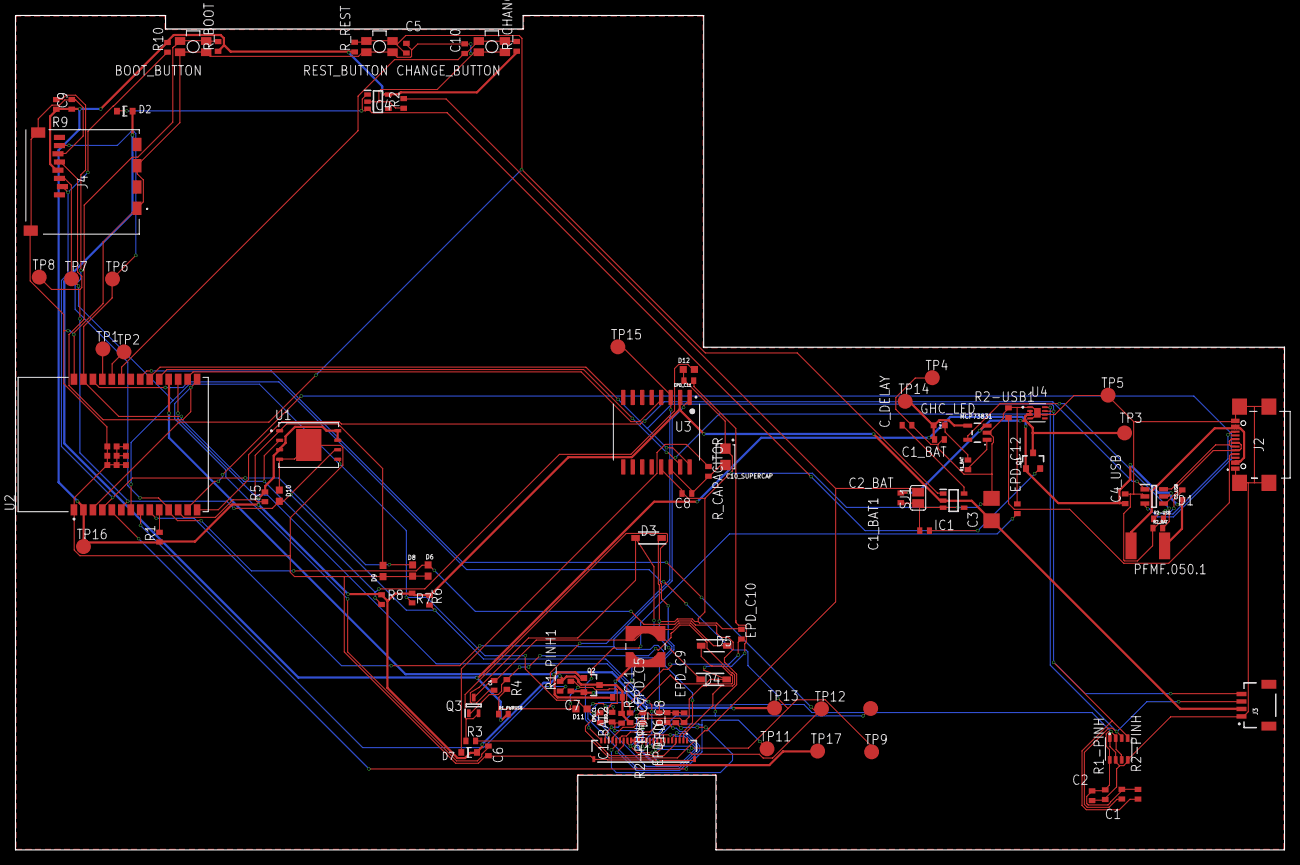
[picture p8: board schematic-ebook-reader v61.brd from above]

Board: 2 copper layers, 170.1 x 111.8 mm, 103 parts (0 on the bottom side), 55 nets.

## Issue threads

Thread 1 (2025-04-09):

Decupare antena

BogdanCiocea, 2025-04-09:
Partea cu antena componentei ESP32-C6-WROOM-1-N8 nu e decupata.  Si, de asemenea, ai fire sub antena (big no-no's)

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

Trebuie sa muti firele si sa decupezi partea aia. Sa fie decupat in genul asta

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

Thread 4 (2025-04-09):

Nume Componente

BogdanCiocea, 2025-04-09:
Sunt cateva probleme cu silkscreen-ul unor componente:

## Denumiri care se pun unele peste altele

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

## Denumiri care nu se vad

La asta am vazut ca s-a pus pe bottom
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

## Denumiri care nu se vad **bine**

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

## Denumiri care se vad partial

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

Closed 2025-04-15.

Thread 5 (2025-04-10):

Chichite la schematic

BogdanCiocea, 2025-04-10:
Nu sunt numele sectiunilor trecute in schematic (SD Card, E-Paper Drive Circuit,...etc) si e putin greu de urmarit

Cateva label-uri arata diferit (ba cu Xref on ba cu Xref off)....nu prea arata uniform...nu stiu cum sa zic) si, iarasi, e putin mai greu de urmarit

Unele nume ale componentelor nu se vad (ce am gasit eu a fost la LDO Voltage Regulator si nu am vazut numele "SD0805S020S1R0" si "DMG2305UX-7" sau ai pus "100uF" in loc de "100uF TANT")

La E-Paper Drive Circuit vad ca ai pus numele SI1308EDL-T1-GE3 suprapus cu sectiunea Li-Po Battery Charging Controller. Ai putea, eventual, sa faci textul mai mic sau sa te folosesti de spatiu gol pe care il ai in coltul din dreapta jos in stanga partii unde scrie "schematic-ebook-reader" ca sa mai "aerisesti" sectiunile. Sau mai e cazul la SPI ESD Protection Lines unde ai loc sa pui numele diodelor ca sa fie usor de citit...mai pe scurt, aeriseste un pic sectiunile sa iti incapa numele/label-urile ca sa nu iasa peste

Closed 2025-04-15.

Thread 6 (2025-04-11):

Grosimea placii

BogdanCiocea, 2025-04-11:
Placuta trebuie sa aiba 1mm grosime. Tu ai de 1.6mm ceea ce nu e bine. Trebuie rezolvat!!!!!

Uite cum faci:
Te duci pe Rules->Preferences->Layer stack

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

Te duci pe linia cu Dielectric si setezi acolo materialul:

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

Cam atat

Closed 2025-04-15.

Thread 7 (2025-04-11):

Date incomplete la BOM

BogdanCiocea, 2025-04-11:
Nu ai scris in BOM nici datasheet-ul si nici pretul fiecarei componente. Trebuie sa adaugi.
Recomand sa iei de pe [Mouser]( http://www.mouser.com/) si de pe [Comet](http://www.comet.srl.ro/).

In cazul in care nu gasesti din aceste site-uri, poti sa iei si din altele.

Closed 2025-04-15.

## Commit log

2025-04-01 Add files via upload
    16-wire-errors
2025-04-06 proiect final
    [PnP_schematic-ebook-reader v61_front.csv, schematic-ebook-reader v40.sch, schematic-ebook-reader v61.brd]

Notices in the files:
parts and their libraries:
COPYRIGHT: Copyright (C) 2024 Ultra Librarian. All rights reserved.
